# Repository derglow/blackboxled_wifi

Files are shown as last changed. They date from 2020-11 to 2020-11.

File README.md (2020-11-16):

# blackboxled_wifi
PCB design and esphome code to connect black box LEDs to WiFi.

The PCB serves two functions...
1) Connect 3.3V digital output to transistor to toggle lights on/off
2) Convert 3.3V PWM into a 0-10V analog output

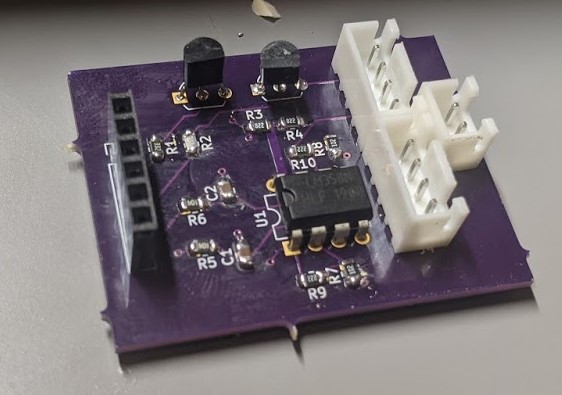
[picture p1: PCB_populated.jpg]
Populated PCB


Parts list:
1) NodeMCU - $4
2) 12V Power Supply - $5
3) PCB - $4

Rough Cost - $13 + a few bucks for components

Link to order the PCBs ($11 for 3):
https://oshpark.com/shared_projects/AcYhgbWN

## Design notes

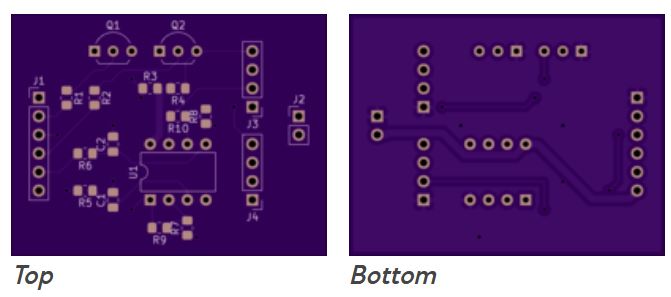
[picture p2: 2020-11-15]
PCB_osh.JPG

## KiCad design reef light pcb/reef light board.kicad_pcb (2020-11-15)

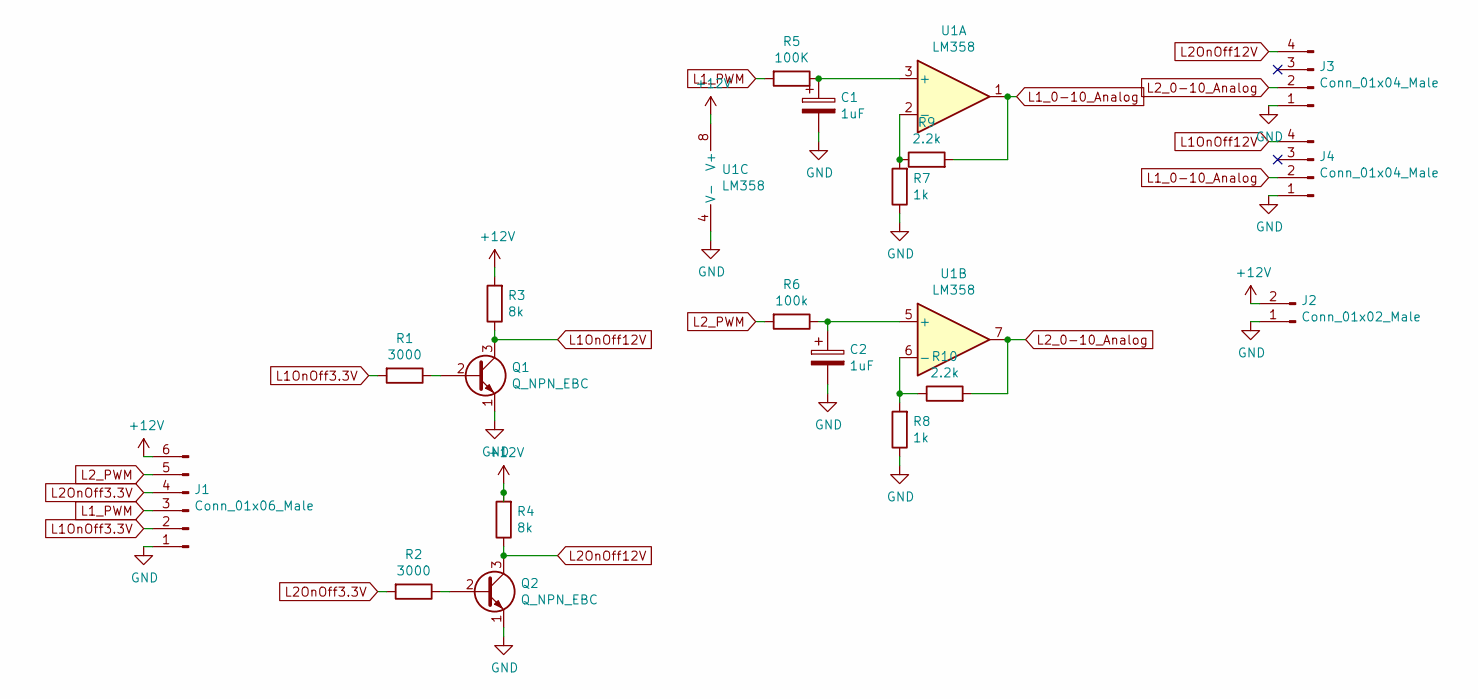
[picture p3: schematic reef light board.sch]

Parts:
C1, C2: 1uF; C_0805_2012Metric_Pad1.18x1.45mm_HandSolder
J1: Conn_01x06_Male; PinHeader_1x06_P2.54mm_Vertical
J2: Conn_01x02_Male; PinHeader_1x02_P2.54mm_Vertical
J3, J4: Conn_01x04_Male; PinHeader_1x04_P2.54mm_Vertical
Q1, Q2: Q_NPN_EBC; TO-92L_Inline_Wide
R1, R2: 3000; R_0805_2012Metric_Pad1.20x1.40mm_HandSolder
R3, R4: 8k; R_0805_2012Metric_Pad1.20x1.40mm_HandSolder
R5: 100K; R_0805_2012Metric_Pad1.20x1.40mm_HandSolder
R6: 100k; R_0805_2012Metric_Pad1.20x1.40mm_HandSolder
R7, R8: 1k; R_0805_2012Metric_Pad1.20x1.40mm_HandSolder
R9, R10: 2.2k; R_0805_2012Metric_Pad1.20x1.40mm_HandSolder
U1: LM358; DIP-8_W7.62mm_LongPads

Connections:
+12V: J1.6, J2.2, R3.2, R4.2, U1.8 (V+)
GND: C1.2, C2.2, J1.1, J2.1, J3.1, J4.1, Q1.1 (E), Q2.1 (E), R7.1, R8.1, U1.4 (V-)
L1OnOff3.3V: J1.2, R1.2
L1OnOff12V: J4.4, Q1.3 (C), R3.1
L1_0-10_Analog: J4.2, R9.2, U1.1
L1_PWM: J1.3, R5.2
L2OnOff3.3V: J1.4, R2.2
L2OnOff12V: J3.4, Q2.3 (C), R4.1
L2_0-10_Analog: J3.2, R10.2, U1.7
L2_PWM: J1.5, R6.2
unnamed: C1.1, R5.1, U1.3 (+)
unnamed: C2.1, R6.1, U1.5 (+)
unnamed: Q1.2 (B), R1.1
unnamed: Q2.2 (B), R2.1
unnamed: R7.2, R9.1, U1.2 (-)
unnamed: R8.2, R10.1, U1.6 (-)

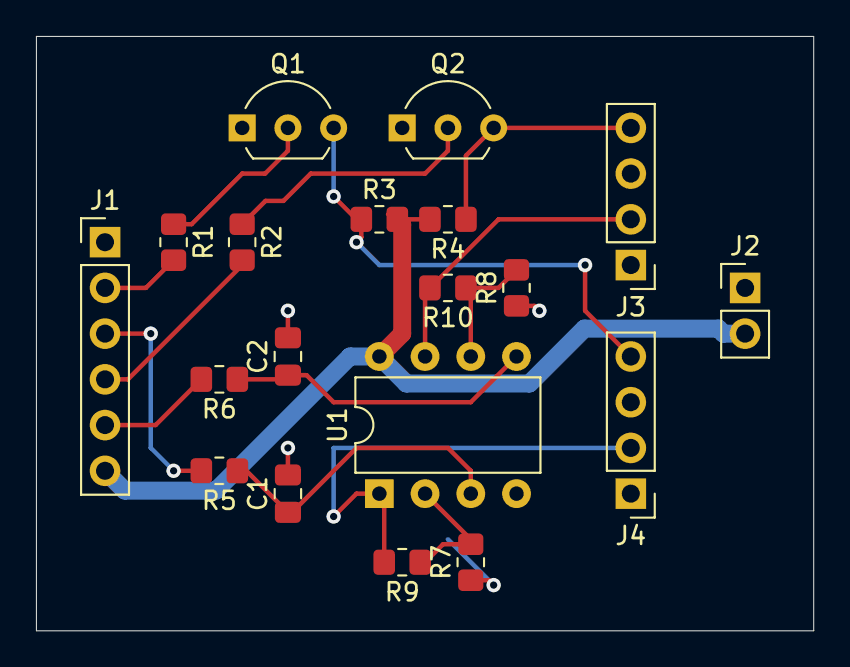
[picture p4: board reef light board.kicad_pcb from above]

Board: 2 copper layers, 43.2 x 33.0 mm, 19 parts (0 on the bottom side), 16 nets.

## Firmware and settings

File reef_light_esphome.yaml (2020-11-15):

esphome:
  name: reeflight_1
  platform: ESP8266
  board: nodemcu

wifi:
  ssid: "YourWifi"
  password: "YourWifiPass"

  # Enable fallback hotspot (captive portal) in case wifi connection fails
  ap:
    ssid: "Reeflight 1 Fallback Hotspot"
    password: "Password"

captive_portal:

# Enable logging
logger:

# Enable Home Assistant API
api:

ota:

power_supply:
  - id: 'power_supply_white'
    pin: 
      number: D8
      inverted: true
    keep_on_time: 
      milliseconds: 100
  - id: 'power_supply_blue'
    pin: 
      number: D6
      inverted: true
    keep_on_time: 
      milliseconds: 100

output:
  - platform: esp8266_pwm
    pin: D7
    power_supply: power_supply_white
    frequency: 1000 Hz
    id: pwm_white
  - platform: esp8266_pwm
    pin: D5
    power_supply: power_supply_blue
    frequency: 1000 Hz
    id: pwm_blue

light:
  - platform: monochromatic
    output: pwm_white
    name: "Reef Light 1 White"
    gamma_correct: 1
    default_transition_length: 5s
  - platform: monochromatic
    output: pwm_blue
    name: "Reef Light 1 Blue"
    gamma_correct: 1
    default_transition_length: 5s
